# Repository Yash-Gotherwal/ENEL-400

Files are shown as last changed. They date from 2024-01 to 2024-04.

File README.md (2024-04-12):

Capstone project repository

Schematics - Design Schematics, pictorial diagram and flowchart and pcb attempt

Hexapod 3d design STL - STL files for 3d printing

ENEL 417 docs - Project Documentation and Arduino sketches for Hexapod.

-Final_hexapod_code - Main code for Hexapod

-Hm10_base_sketch - inital code for testing bluetooth module using breadboard circuit

-Prototype_leg_with_individual_servo - initial code for testing leg movement using servodriver and bluetooth

Datasheets - component datasheets

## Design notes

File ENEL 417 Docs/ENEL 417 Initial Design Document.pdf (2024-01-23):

# SpyderSense

Yash Gotherwal

Selamawit Temnewo

## Table of Contents

## Project Description:

In response to Regina's pressing challenge with hoarder houses hindering emergency responders, our project addresses the need for efficient fire detection. We propose developing a prototype spider bot equipped with thermal sensing capabilities to detect and relay thermal hotspots, facilitating strategic resource allocation. The project also incorporates a camera for navigation purposes. The spider-bot will be remotely controlled, ensuring user convenience in navigating cluttered environments. Our goals encompass cost-effectiveness, compact size, manageable weight, good battery life, regulatory compliance and a commitment to minimizing environmental impact. The spider bot aims to be a versatile and effective solution for enhancing safety and rescue operations in challenging environments.

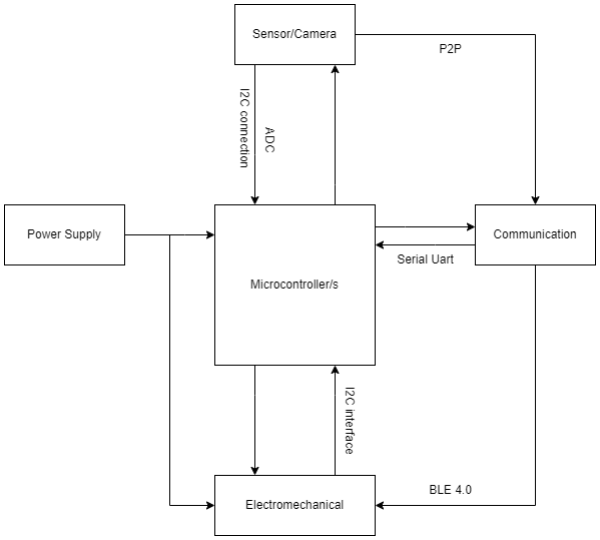
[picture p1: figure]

Fig 1. Block Diagram Hexapod

The block diagram above shows the basic components that are needed to set up the Spider Bot. The microcontroller is the base control for the robot. The power supply component gives power to the microcontroller and the electromechanical (Robot) part separately to avoid damaging the microcontroller. The communication module communicates using BLE 4.0 and Serial uart. The Electromechanical (Robot) part has servo drivers which will use I2C interface to communicate with the microcontroller. For the camera and sensors, we plan to use I2C (camera), P2P (wifi) and ADC (sensor) protocols.

## Project Specifications

As a team working on this project together, we need to consider various specifications that apply to different parts of our overall goal. Here's a starting list of specifications that will guide the development of the hexapod.

### Physical specifications:

- Weight:
- Overall weight needs to be as light as possible considering the heavy servos in order to make the robot movement as smooth as possible. By previous estimations we are aiming for the robot to be around 3-3.5KG
- Material:
- Use lighter but durable material Such as ABA for design with a 50-60 infill for durability.
- Legs DOF:
- Considering the heavy build a 6-legged spider bot with 3 DOF (Degrees of Freedom) per leg would be a better choice than a 4-legged version as if rough terrain is to be navigated the bot might need to be up on 2 legs at a time and being a 6-legged design the extra two legs should provide stability to the robot.
- LM35:
- Temperature range of –55°C to 150°C.
- Camera module (0v7670):
- 0.3MP resolution, VGA (640 x 480)

### Performance specifications:

- Servo power consumption:
- According to the MG996r datasheet and initial testing calculations the operating current of the servo is in the range of 500-900mA with current spikes reaching 1.1A on moderate load. Operating voltage for the servos is 4.8-7V.
- Battery life:
- The final aim of the prototype is to aim for a battery life of 15-30 min.
- Image Transmission:
- Minimum Bandwidth requirement of 0.407 bits per second
- Range:
- Aiming to achieve 30-50m Range (HM-10 module has open space range of 100m according to datasheet)

### Protocol Specifications:

- Communication protocols:
- The PCA9685 Servo driver uses I2C communication. (pin 20-21)
- HM10 Bluetooth module needs uart and BLE 4.0. (pin 0-1)
- Control interface:
- Android 4.0 application.
- LM35:
- Uses ADC to communicate with microcontroller
- ESP8266:
- Uses TCP/IP networking
- Camera Module (0v7670):
- Uses Serial camera control bus (SCCB) which is an I2C protocol.

## Workload

The workload distribution for our group is as follow:

Yash: -Responsible for hexapod design and construction and Bluetooth functionality

-Integration of final components.

Selam: -Responsible for Circuit building and designing for camera and thermal sensor module.

## Testing plan

Based on the workload distribution the testing plan of each individual team member is as follows:

Yash (Electromechanical, communication, power supply):

- Servo Motor Testing:
- Connect servo motors to PCA9685 and control multiple servos. (√)
- Measuring operating, peak and hold current for servos. (√ - except hold current)
- Calibrate each servo to a 0° angle to make it easier for testing leg movement.
- Power Supply Testing:
- Connect 9 servo motors to the same power supply.
- Confirm that the power supply can handle the load of all connected servos.
- Monitor for any fluctuations or issues in servo movements during simultaneous operation.
- Check to see if bench supply is good or is it better to use a buck converter. (Find old buck convertor from previous toolbox)
- Initial Robot Build and Code Testing (Start before Fall Break):
- Begin the physical construction of the hexapod robot during the Fall break. (√ - leg design submitted and waiting on reply from workshop)
- Test the code implementation on the microcontroller for basic functionalities.
- Identify and address any early issues with the build or code.
- Robot Mobility Testing without Bluetooth:
- Test the movement of the robot without the Bluetooth module.
- Ensure that the servos can handle the load and move the robot effectively.
- Check for any mechanical issues or constraints affecting mobility.
- Communication Module Testing:
- Verify the reliability of communication between the microcontroller and the Bluetooth module.
- Bluetooth Implementation and Controller/Android Application Decision:
- Implement the code to utilize the Bluetooth module for robot movement.
- Test the movement using a controller (if chosen) or an Android application.

Selam: (Camera, Sensor, Communication, Power supply)

- Camera Integration and Image Transmission:
- Connect the camera to the microcontroller.
- Write code to capture an image using the camera.
- Measure the time taken for the entire process of capturing and sending the image.
- Temperature Sensor Integration and Reading:
- Connect the temperature sensor to the microcontroller.
- Develop a small program to read temperature data from the sensor.
- Display the temperature information on the microcontroller.
- Wi-Fi Communication Setup:
- Connect a Wi-Fi module to the microcontroller.
- Write code to enable communication between the microcontroller, camera, and temperature sensor through Wi-Fi.
- Ensure the microcontroller can send both the picture and temperature information to an app or cloud-based system.
- Computer Display Check:
- Set up a remote-control system for the project on your computer.
- Verify that the microcontroller sends the captured picture and temperature information to the computer screen.
- Power Consumption Check:
- Verify that the camera, temperature sensor, and microcontroller are adequately powered.
- Measure the power consumption of each component during operation.
- Integration Test:
- Combine the camera, temperature sensor, and Wi-Fi modules into one integrated system.
- Test the overall functionality, ensuring smooth operation when all components are working together.

## Gantt Chart:

Below is an attached gantt chart that was created for ENEL 400. So Far, we look to be on the correct track.

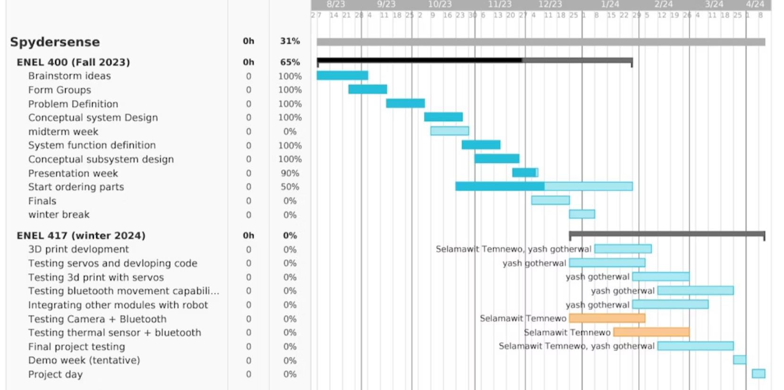
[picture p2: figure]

## Budget:

As this is a self-funded project the budget options were discussed with Dr. Paul Laforge. Upon discussion we concluded that the budget would be around $200 per person (cost of 2 textbooks per semester) so the overall budget is $400.

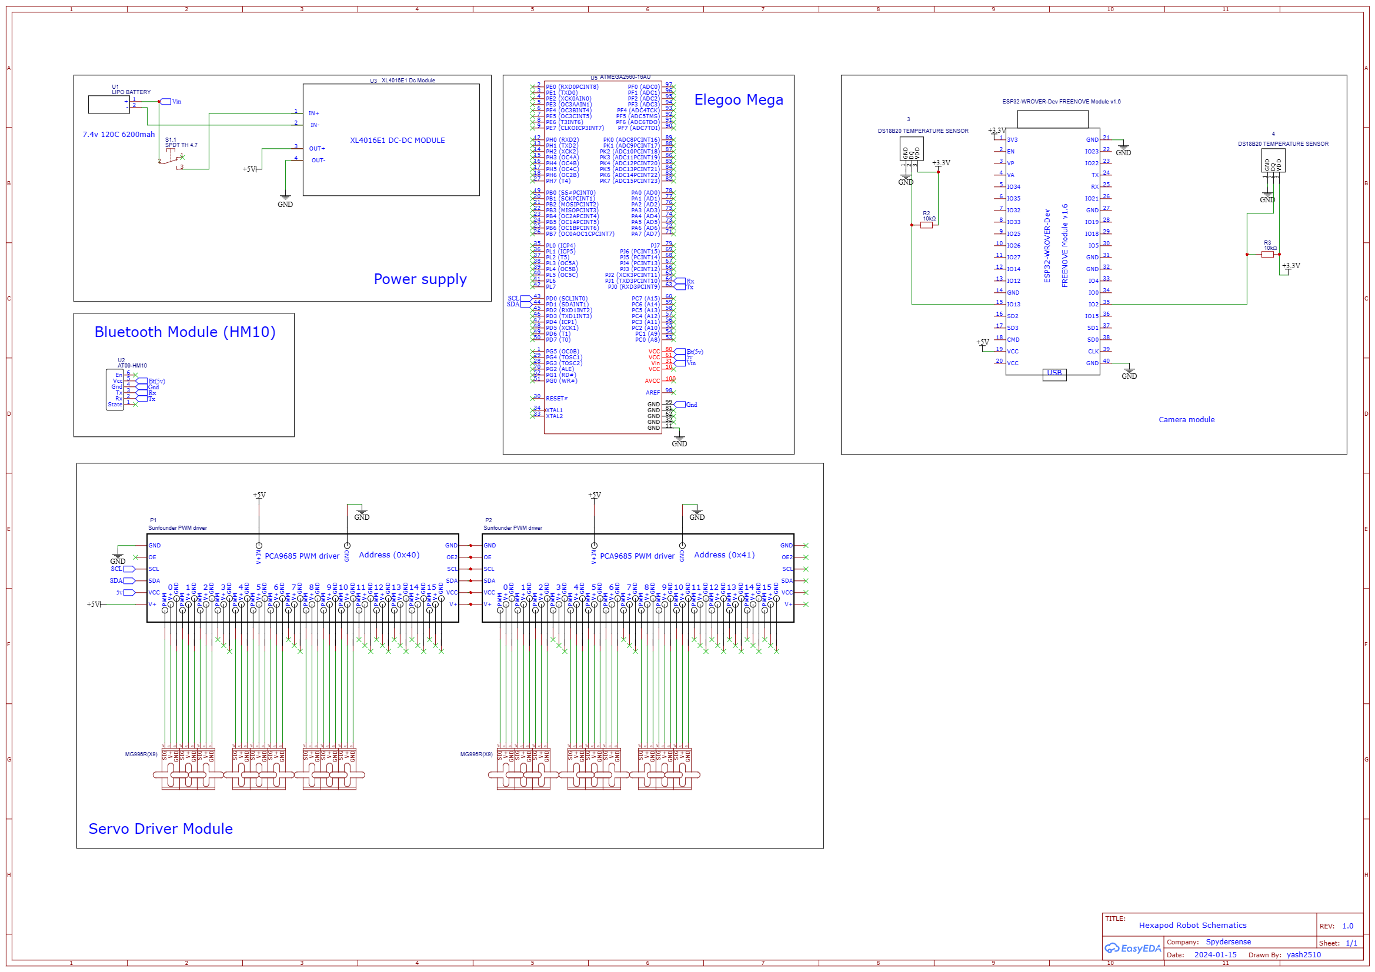
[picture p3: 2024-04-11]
Schematic/Schematic_Hexapod-Schematics_2024-04-11.png

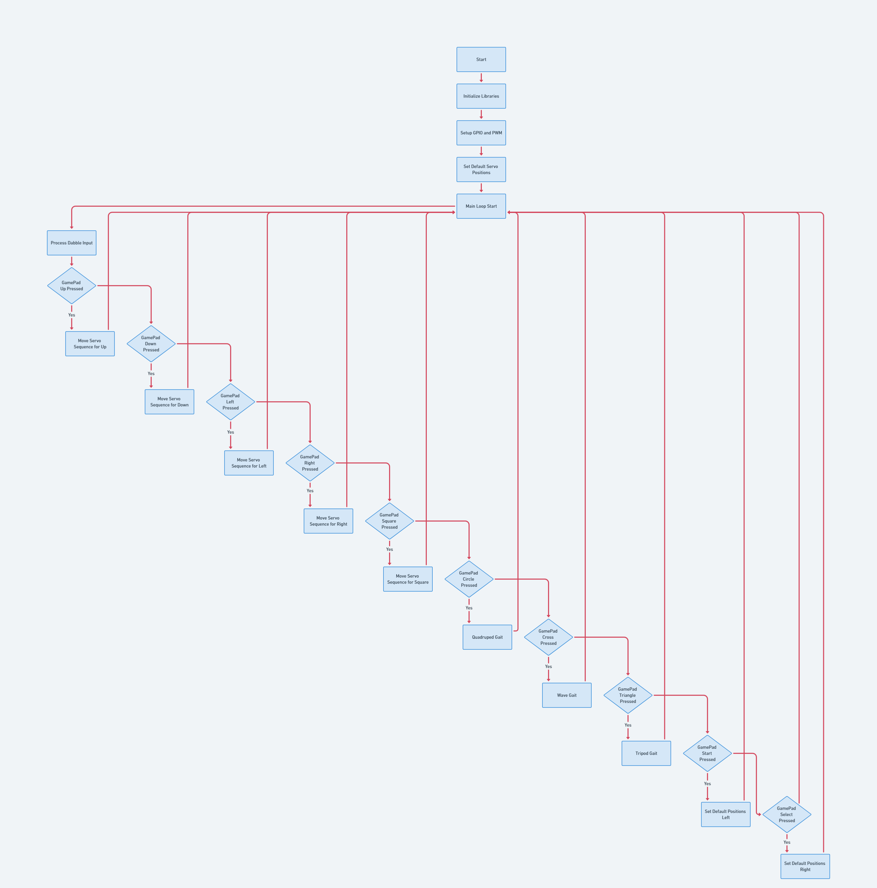
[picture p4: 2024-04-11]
Schematic/Servo Control System.png

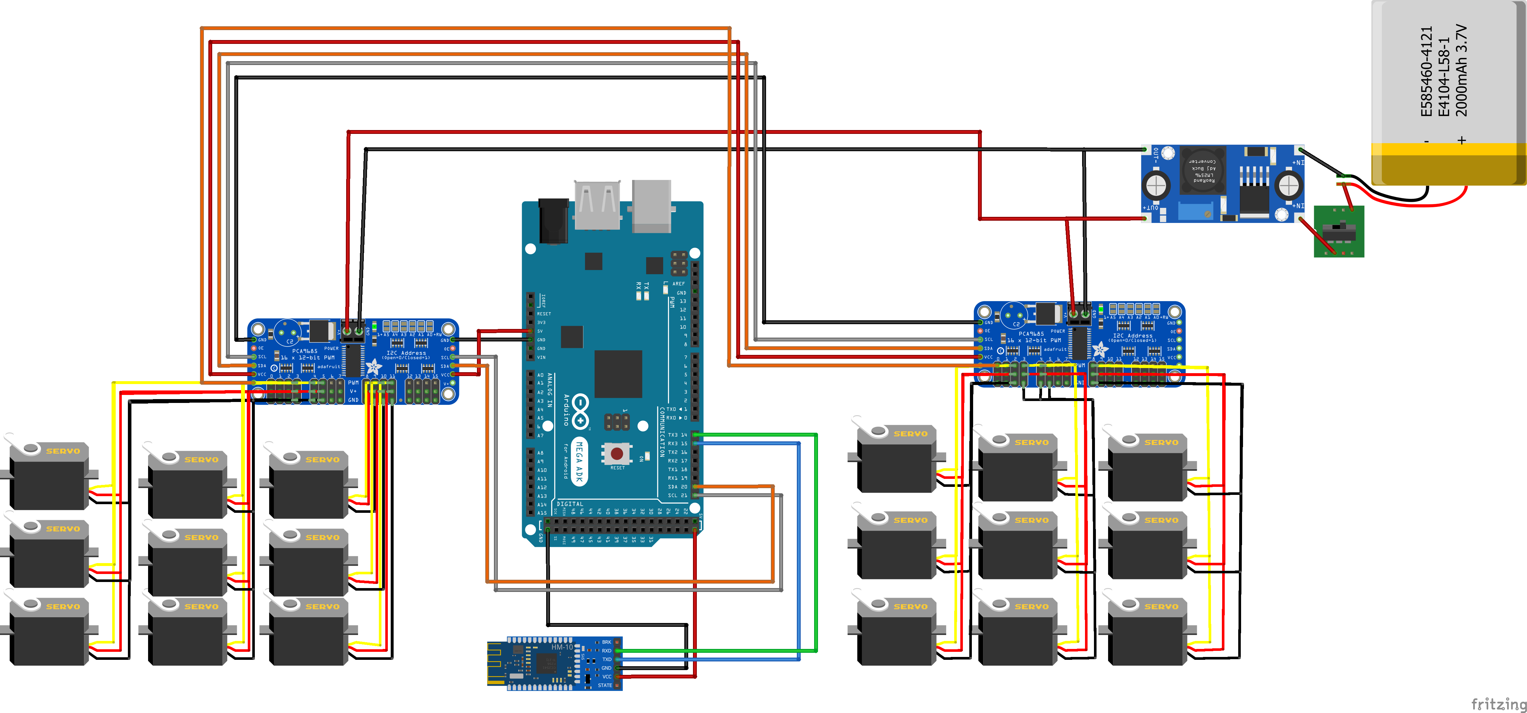
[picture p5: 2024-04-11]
Schematic/Final pictorial diagram.png

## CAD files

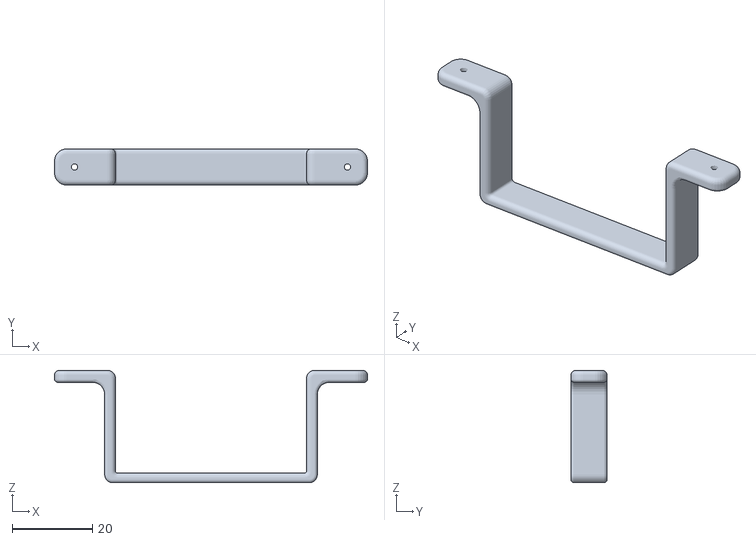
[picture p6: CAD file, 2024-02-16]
Hexapod 3d STL files/battery-bar.stl
78.0 x 9.00 x 28.0

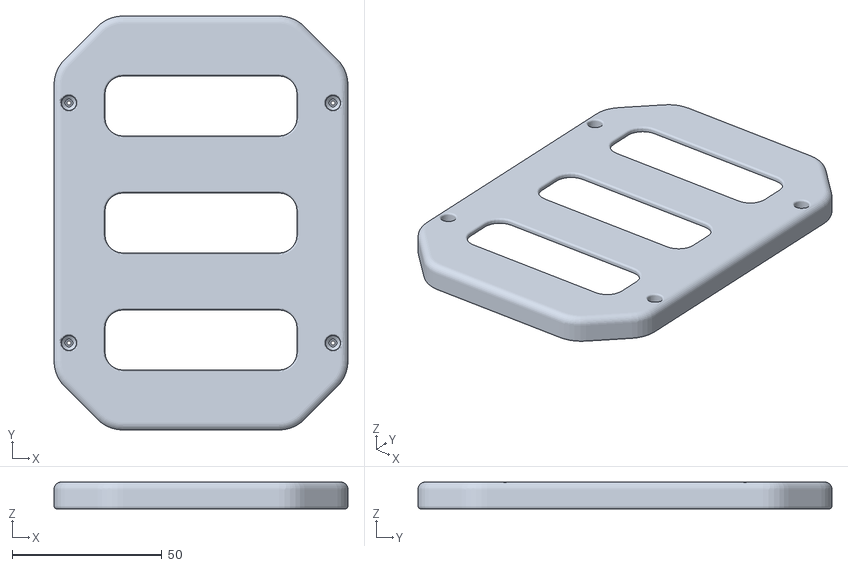
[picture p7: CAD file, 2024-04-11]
Hexapod 3d STL files/Revised Stl/top-cover.stl
98.0 x 138.0 x 9.00

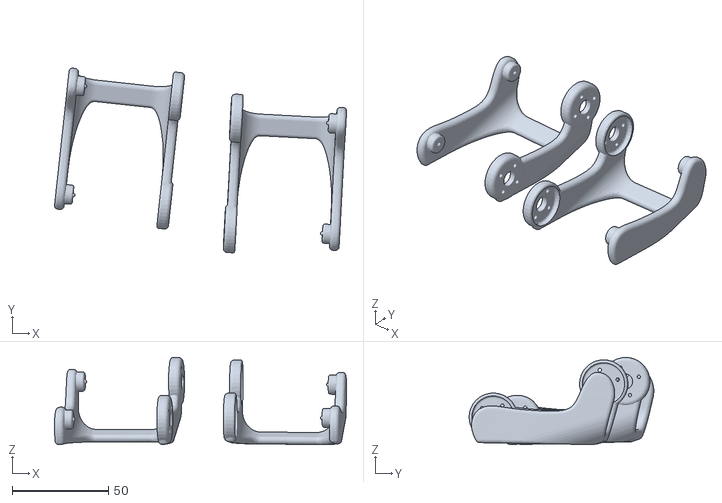
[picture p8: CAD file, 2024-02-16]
Hexapod 3d STL files/Revised Stl/Femur - mirrored.stl
151.7 x 95.9 x 45.2

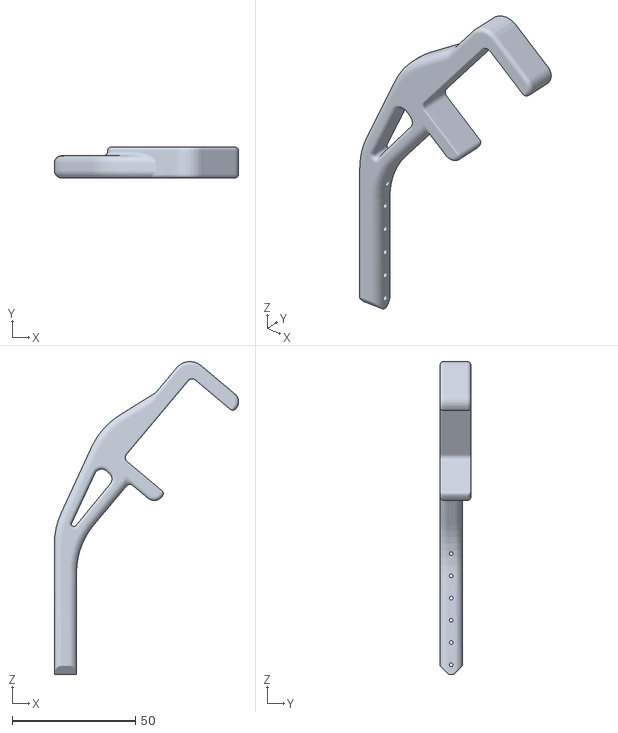
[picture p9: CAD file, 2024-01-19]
Hexapod 3d STL files/right-tibia.stl
74.6 x 12.5 x 126.7

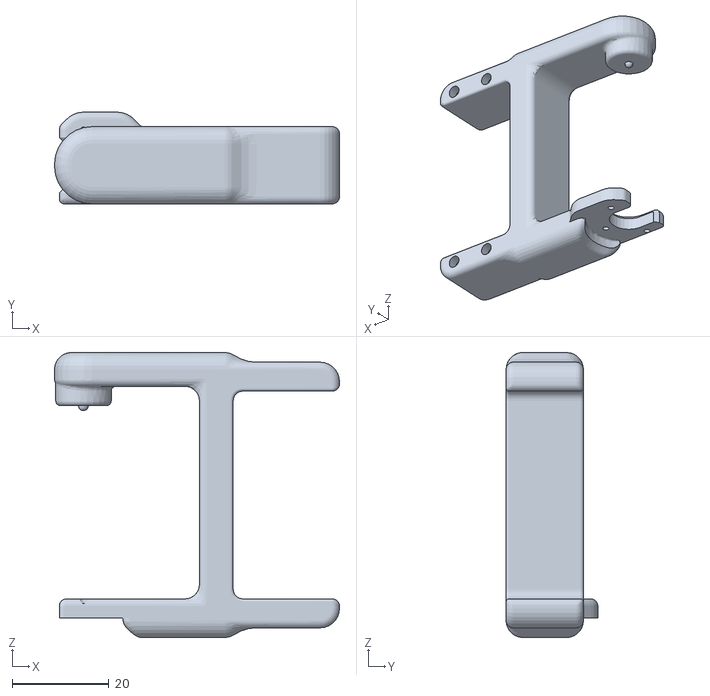
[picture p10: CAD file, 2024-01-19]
Hexapod 3d STL files/left-coxa2.stl
59.0 x 19.0 x 59.0

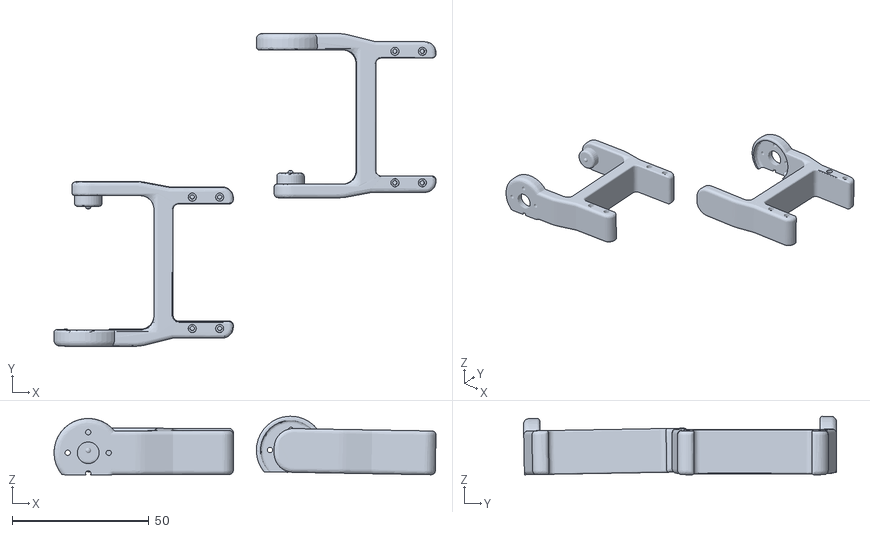
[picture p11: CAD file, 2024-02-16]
Hexapod 3d STL files/Revised Stl/Coxa - mirrored.stl
139.5 x 114.3 x 21.4

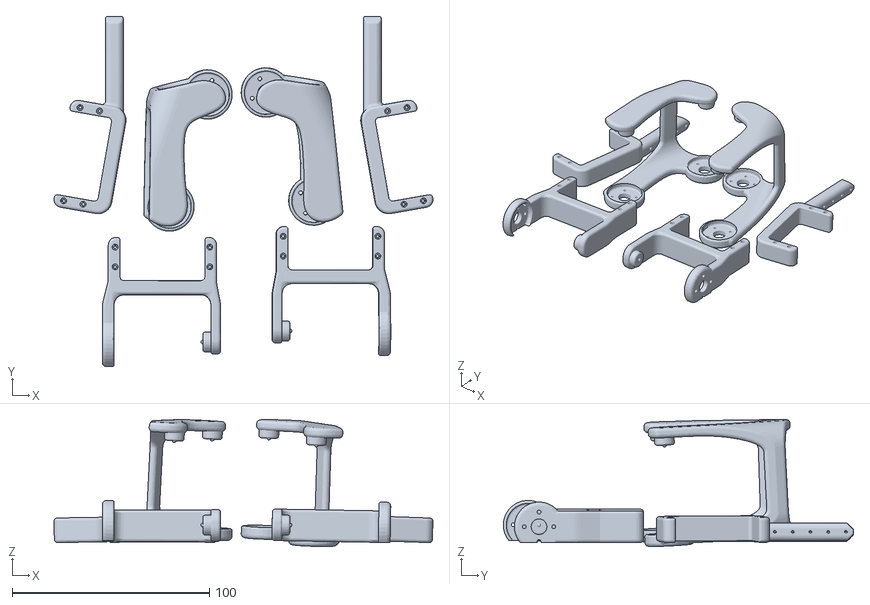
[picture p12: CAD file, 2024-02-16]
Hexapod 3d STL files/Revised Stl/Mirrored parts combined.stl
192.2 x 177.7 x 64.5

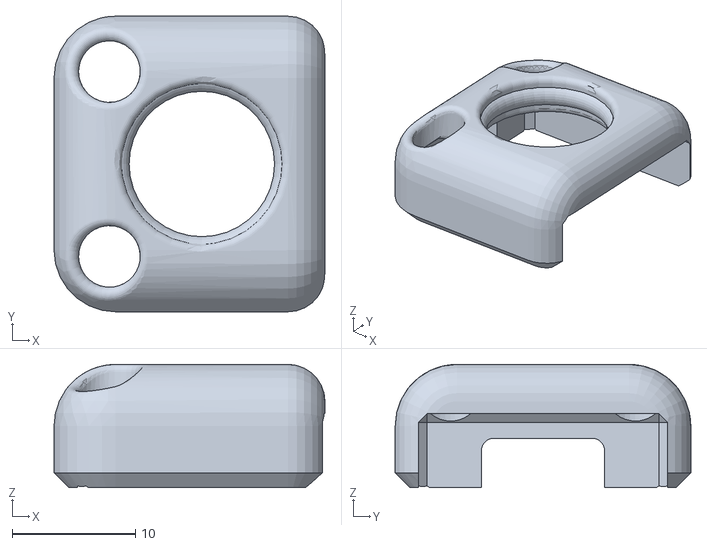
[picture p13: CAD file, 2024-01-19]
Hexapod 3d STL files/servo-back-hole2.stl
22.0 x 24.0 x 10.0

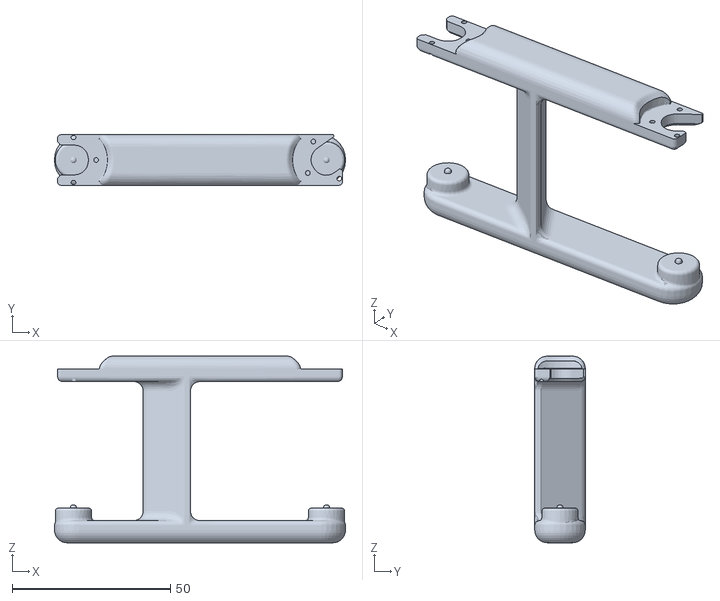
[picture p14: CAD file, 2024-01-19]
Hexapod 3d STL files/left-femur.stl
92.0 x 16.0 x 59.0

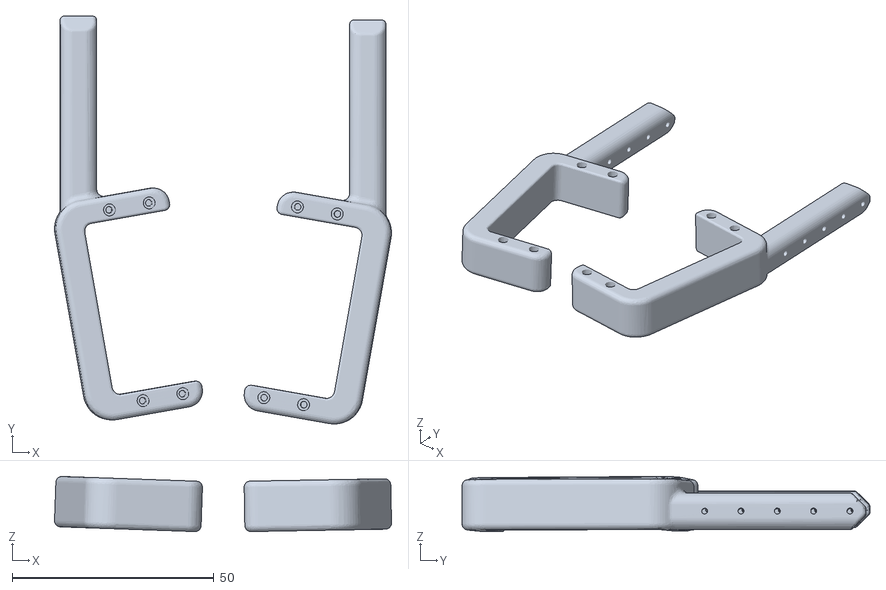
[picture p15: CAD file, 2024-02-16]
Hexapod 3d STL files/Revised Stl/Tibia - mirrored.stl
83.5 x 101.1 x 13.6

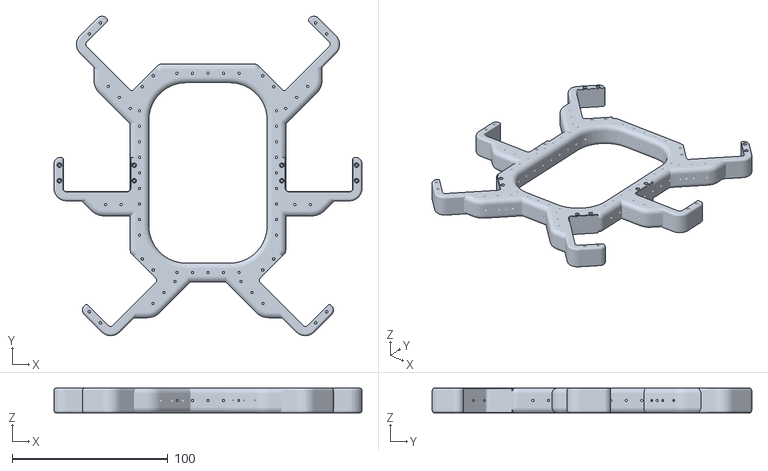
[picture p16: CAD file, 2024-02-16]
Hexapod 3d STL files/Revised Stl/frame.stl
198.0 x 205.4 x 16.0

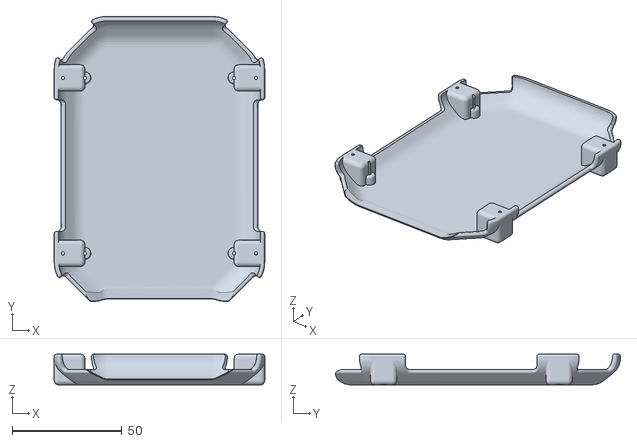
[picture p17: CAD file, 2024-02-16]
Hexapod 3d STL files/Revised Stl/bottom-cover-flat.stl
96.0 x 130.0 x 14.0

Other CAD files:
Hexapod 3d STL files/left-tibia.stl
Hexapod 3d STL files/right-femur.stl
Hexapod 3d STL files/right-coxa2.stl

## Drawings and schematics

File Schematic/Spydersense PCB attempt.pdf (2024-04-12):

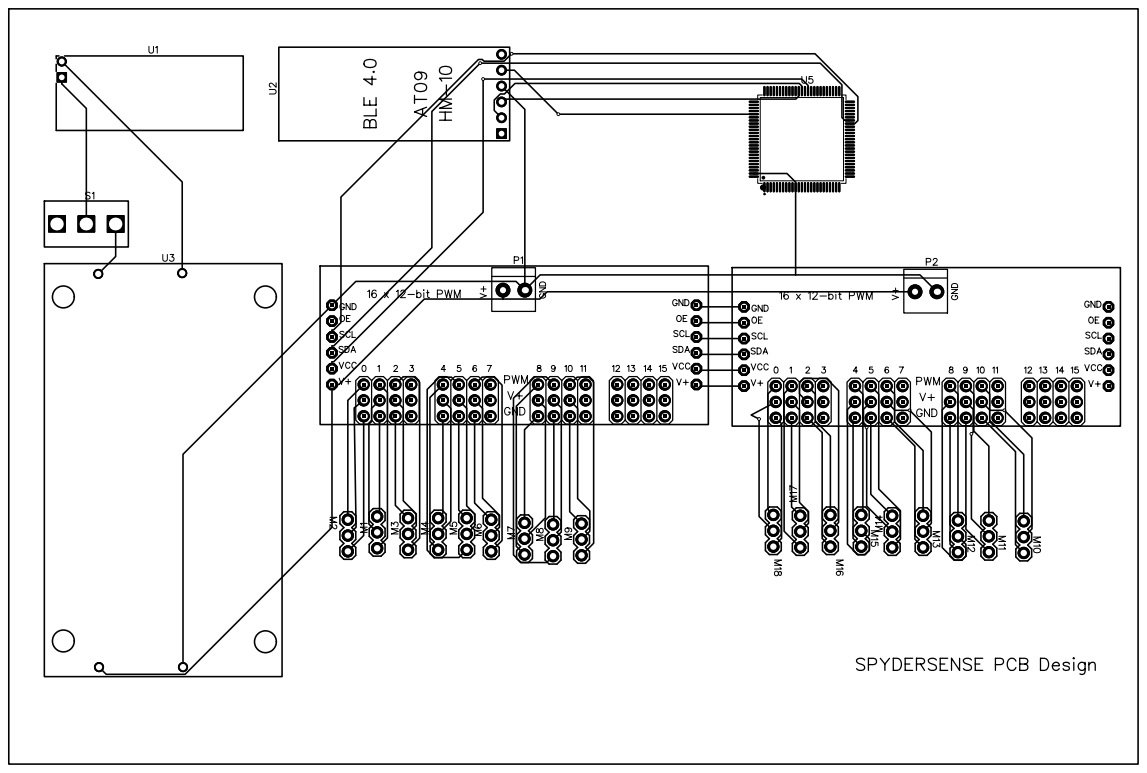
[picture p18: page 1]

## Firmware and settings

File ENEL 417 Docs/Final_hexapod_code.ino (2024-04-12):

/*Final code for Hexapod robot
Student name: Yash Gotherwal
Student ID: 200420786

This is the final code for the hexapod robot for my final capstone project.

Several changes were made from the initial commit
The final commit includes cleaning up code and adding documentation and comments
*/
#include <Wire.h>
#include <Adafruit_PWMServoDriver.h>
#include <math.h>
#include "Servo.h"

#define CUSTOM_SETTINGS
#define INCLUDE_GAMEPAD_MODULE
#include <Dabble.h>

Adafruit_PWMServoDriver pwm = Adafruit_PWMServoDriver(0x40);  //Initialize servodriver for left side legs with address (0x40)
Adafruit_PWMServoDriver pwm1 = Adafruit_PWMServoDriver(0x41); //Initialize servodriver for right side legs with address (0x41)
#define SERVOMIN  140 // This is the 'minimum' pulse length count (out of 4096)  
#define SERVOMAX  620 // This is the 'maximum' pulse length count (out of 4096)
#define SERVO_FREQ 60 // Analog servos run at ~50 Hz updates

//servo # counter
const int servoCountLeft = 9;
const int servoPinsLeft[9] = {0, 1, 2, 3, 4, 5, 6, 7, 8}; //Array to store left side servos
const int servoCountRight = 9;
const int servoPinsRight[9] = {0, 1, 2, 3, 4, 5, 6, 7, 8};  //Array to store right side servos

/*left legs servo orientation
6 7 8 - leg 3 (Tibia,Femur,Coxa) /\_
3 4 5 - leg 2 (Tibia,Femur,Coxa) /\_
0 1 2 - leg 1 (Tibia,Femur,Coxa) /\_
*/
int defaultPositionsLeft[servoCountLeft] = {80, 120, 90, 100, 130, 80, 110, 150, 120};  //Default servo positions for left legs
int servoAnglesLeft[servoCountLeft];
/*Right legs servo orientation
2 1 0 - leg 4 (Coxa,Femur,Tibia) _/\
5 4 3 - leg 5 (Coxa,Femur,Tibia) _/\
8 7 6 - leg 6 (Coxa,Femur,Tibia) _/\
*/
int defaultPositionsRight[servoCountRight] = {100, 80, 50, 160, 90, 50, 160, 90, 50};   //Default servo positions for right legs
int servoAnglesRight[servoCountRight];



void setup() {
  Serial.begin(9600);
  Serial.println("8 channel Servo test!");
  Dabble.begin(9600);

  pwm.begin();  //begin serial communication for servo drivers
  pwm1.begin();
 
  pwm.setOscillatorFrequency(25000000);
  pwm.setPWMFreq(SERVO_FREQ);  
  pwm1.setOscillatorFrequency(25000000);
  pwm1.setPWMFreq(SERVO_FREQ);
  setDefaultPositions();
}

void loop() {
   Dabble.processInput();             //this function is used to refresh data obtained from smartphone.
  
  if (GamePad.isUpPressed())  // Wave function
  {
    moveServoLeft(1,50);
    moveServoLeft(0,180);
    for(int i = 0; i < 3; i++)
    {
      moveServoLeft(2,60);
      moveServoLeft(2,120);
    }
  }
  if (GamePad.isDownPressed())  //move leg 3 and leg 6 Femur up
  {
    moveServoRight(7,140); 
    moveServoLeft(7,80);
  }

  if (GamePad.isLeftPressed())  //move leg 1 and leg 4 Femur up
  {
    moveServoLeft(1,100);
    moveServoRight(1,130);
  }
   if (GamePad.isRightPressed())  //move leg 2 and leg 5 Femur up
  {
    moveServoRight(4,160);
    moveServoLeft(4,100); 
  }
  if (GamePad.isSquarePressed())  //Bow 
  {
    moveServoLeft(0,130);
    moveServoLeft(1,90);
    moveServoRight(7,140);
    moveServoRight(6,40);
  }

  if (GamePad.isCirclePressed()) // Quadruped gait function
  {
    QuadrupedGait();
  }

  if (GamePad.isCrossPressed()) //Wave gait function 
  {
    WaveGait();
  }

  if (GamePad.isTrianglePressed()) //Tripod gait function
  {
    TripodGait();
  }

  if (GamePad.isStartPressed()) // set left servos to default position
  {
    setDefaultPositionsLeft();
  }

  if (GamePad.isSelectPressed()) // set right servos to default position
  {
    setDefaultPositionsRight();
  }
}

void moveServoLeft(int servoIndex, int targetAngle) //Function to move left side servos depending on their index numbers
{
  // Smoothly move the servo to the target angle
  for (int i = servoAnglesLeft[servoIndex]; i != targetAngle; i += (targetAngle > i) ? 1 : -1)
  {
    servoAnglesLeft[servoIndex] = i;
    pwm.setPWM(servoPinsLeft[servoIndex], 0, angleToPulse(i));
    delay(10); // Adjust the delay for smoother motion
  }
}

void moveServoRight(int servoIndex, int targetAngle) //Function to move right side servos depending on their index numbers
{
//   // Smoothly move the servo to the target angle
  for (int i = servoAnglesRight[servoIndex]; i != targetAngle; i += (targetAngle > i) ? 1 : -1)
  {
  servoAnglesRight[servoIndex] = i;
  pwm1.setPWM(servoPinsRight[servoIndex], 0, angleToPulse(i));
  delay(10); // Adjust the delay for smoother motion
  }
}


void setDefaultPositions() //Set all servos to default position--> runs once at the beginning of code
{
  // Set all servos to their default positions
  for (int i = 0; i < servoCountLeft; i++)
  {
    moveServoLeft(i, defaultPositionsLeft[i]);
  }
  delay(10);
  for (int i = 0; i < servoCountRight; i++)
  {
    moveServoRight(i, defaultPositionsRight[i]);
  }
}
void setDefaultPositionsLeft() //Returns all left servos to default position
{
    for (int i = 0; i < servoCountLeft; i++)
  {
    moveServoLeft(i, defaultPositionsLeft[i]);
  }
  delay(10);
}

void setDefaultPositionsRight() //Returns all right servos to default positions
{
  for (int i = 0; i < servoCountRight; i++)
  {
    moveServoRight(i, defaultPositionsRight[i]);
  }
  delay(10);
}

int angleToPulse(int angle) //Inbuilt library function to map frequency to 0-180°
{
  // Convert angle to servo pulse length
  return map(angle, 0, 180, SERVOMIN, SERVOMAX);
}

void moveleg1() //Servo coordinated function to move leg 1 
{
  moveServoLeft(0,130);
  delay(150);
  moveServoLeft(1,90);
  delay(150);
  moveServoLeft(2,30);
  delay(150);
  moveServoLeft(1,125);
  delay(150);
  moveServoLeft(0,80);
  delay(150);
  moveServoLeft(2,110);
  delay(150);
}

void moveleg2() //Servo coordinated function to move leg 2
{
  moveServoLeft(3,150);
  delay(150);
  moveServoLeft(4,90);
  delay(150);
  moveServoLeft(5,30);
  delay(150);
  moveServoLeft(4,140);
  delay(150);
  moveServoLeft(3,105);
  delay(150);
  moveServoLeft(5,130);
}

void moveleg3() //Servo coordinated function to move leg 3
{
  moveServoLeft(6,150);
  delay(150);
  moveServoLeft(7,110);
  delay(150);
  moveServoLeft(8,60);
  delay(150);
  moveServoLeft(7,155);
  delay(150);
  moveServoLeft(6,110);
  delay(150);
  moveServoLeft(8,150);
}

void moveleg4() //Servo coordinated function to move leg 4
{
  moveServoRight(1,120);
  delay(150);
  moveServoRight(0,40);
  delay(150);
  moveServoRight(2,70);
  delay(150);
  moveServoRight(1,70);
  delay(150);
  moveServoRight(0,110);
  delay(150);
  moveServoRight(2,30);
}

void moveleg5() //Servo coordinated function to move leg 5
{
  moveServoRight(4,100);
  delay(150);
  moveServoRight(3,40);
  delay(150);
  moveServoRight(5,90);
  delay(150);
  moveServoRight(4,80);
  delay(150);
  moveServoRight(3,160);
  delay(150);
  moveServoRight(5,20);
}

void moveleg6() //Servo coordinated function to move leg 6
{
  moveServoRight(7,120);
  delay(150);
  moveServoRight(6,40);
  delay(150);
  moveServoRight(8,120);
  delay(150);
  moveServoRight(7,70);
  delay(150);
  moveServoRight(6,150);
  delay(150);
  moveServoRight(8,50);
}

void TripodGait() //Loops leg movement in tripod gait 2 times
{
  for(int i = 0;i < 2; i++)
  {
  moveleg1();
  moveleg3();
  moveleg5();
  moveleg2();
  moveleg4();
  moveleg6();
  setDefaultPositions();
  }
}

void QuadrupedGait() //Loops leg movement in Quadruped gait 2 times
{
   for(int i = 0;i < 2; i++)
  {
  moveleg1();
  moveleg4();
  moveleg5();
  moveleg3();
  moveleg6();
  moveleg2();
  setDefaultPositions();
  }
}

void WaveGait() //Loops leg movement in wave gait 2 times
{
  for(int i = 0; i < 2;i++)
  {
    moveleg4();
    moveleg5();
    moveleg6();
    setDefaultPositionsRight();
    moveleg3();
    moveleg2();
    moveleg1();
    setDefaultPositionsLeft();
  }
}

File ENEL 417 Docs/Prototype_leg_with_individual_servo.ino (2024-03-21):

#include <Wire.h>
#include <Adafruit_PWMServoDriver.h>
#define CUSTOM_SETTINGS
#define INCLUDE_GAMEPAD_MODULE
#include <Dabble.h>

// called this way, it uses the default address 0x40
Adafruit_PWMServoDriver pwm = Adafruit_PWMServoDriver();
#define SERVOMIN  150 // This is the 'minimum' pulse length count (out of 4096)
#define SERVOMAX  600 // This is the 'maximum' pulse length count (out of 4096)
#define SERVO_FREQ 60 // Analog servos run at ~50 Hz updates

// our servo # counter
const int servoCount = 3;
const int servoPins[] = {0, 1, 2};

int defaultPositions[servoCount] = {90, 90, 90};
int servoAngles[servoCount];

void setup() {
  Serial.begin(9600);
  Serial.println("8 channel Servo test!");
  Dabble.begin(9600);

  pwm.begin();
 
  pwm.setOscillatorFrequency(27000000);
  pwm.setPWMFreq(SERVO_FREQ);  // Analog servos run at ~50 Hz updates
  
  for (int i = 0; i < servoCount; i++)
  {
    servoAngles[i] = defaultPositions[i];
    pwm.setPWM(servoPins[i], 0, angleToPulse(servoAngles[i]));
  }
  delay(10);
}

void loop() {
   Dabble.processInput();             //this function is used to refresh data obtained from smartphone.Hence calling this function is mandatory in order to get data properly from your mobile.
  Serial.print("KeyPressed: ");
  if (GamePad.isUpPressed())
  {
    moveServo(0,140);
    Serial.print("UP");
  }

  if (GamePad.isDownPressed())
  {
    moveServo(1,150);
    Serial.print("DOWN");
  }

  if (GamePad.isLeftPressed())
  {
    moveServo(2,140);
    moveServo(1,170);
    moveServo(0,150);
    moveServo(2,90);
    moveServo(1,90);
    moveServo(0,90);

    

    Serial.print("Left");
  }
   if (GamePad.isRightPressed())
  {
    moveServo(0,90);
    moveServo(1,90);
    moveServo(2,90);

    Serial.print("Right");
  }

}

void moveServo(int servoIndex, int targetAngle)
{
  // Smoothly move the servo to the target angle
  for (int i = servoAngles[servoIndex]; i != targetAngle; i += (targetAngle > i) ? 1 : -1)
  {
    servoAngles[servoIndex] = i;
    pwm.setPWM(servoPins[servoIndex], 0, angleToPulse(i));
    delay(10); // Adjust the delay for smoother motion
  }
}
void setDefaultPositions()
{
  // Set all servos to their default positions
  for (int i = 0; i < servoCount; i++)
  {
    moveServo(i, defaultPositions[i]);
  }
}

int angleToPulse(int angle)
{
  // Convert angle to servo pulse length
  return map(angle, 0, 180, SERVOMIN, SERVOMAX);
}

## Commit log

2024-01-19 Hexapod legs and calibration tool
    [calibration-arm.stl, calibration-ruler.stl, left-coxa2.stl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]
2024-02-16 Revised stl files final 3d print.
    [Coxa - mirrored.stl, Femur - mirrored.stl, Mirrored parts combined.stl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]
2024-03-07 V1- Base sketch for bluetooth module
    Using HM10 with Dabble app digital gamepad. BLE TX-pin 15, RX-pin 14.
2024-03-07 added digital write for single prototype leg
2024-03-08 V2 - Added single loop for leg movement
2024-03-21 single leg with hm10 initial movement
    initial for stance and swing
2024-03-22 initial code for leg movement
    Connected single driver and tested left legs with initial code for movement need to implement timers for synchronous movements
2024-03-28 Prototype faculty demo
    Added demonstration for quadruple,tripod and wave gait, raising 2 legs at a time, single leg loop movements, default movements and wave.
2024-03-28 Delete Hexapod 3d STL files/calibration-arm.stl
    removed unnecessary stl file
    [calibration-arm.stl]
2024-03-28 Delete Hexapod 3d STL files/calibration-ruler.stl
    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
    [calibration-ruler.stl]
2024-03-28 Initial schematic design.
    Need changes on camera and thermal sensor module
2024-04-06 Last minute commit
    Added square button functionality for leg movement and did default positions for quadrapedle gait
2024-04-11 Flowchart for hexapod
2024-04-11 Delete schematics/Schematic_Hexapod-Schematics_2024-03-28.pdf
    Adding updated schematic
2024-04-11 Delete schematics/Schematic_Hexapod-Schematics_2024-04-11.png
    Adding updated schematics
2024-04-11 Delete schematics directory
    Adding updated stuff
2024-04-11 Update README.md
    deleted old schematics added new
2024-04-11 Updated schematic
    updated flowchart,pictorial diagram and schematic
2024-04-11 top and bottom cover
    [bottom-cover-flat.stl, top-cover.stl]
2024-04-12 PCB attempt
